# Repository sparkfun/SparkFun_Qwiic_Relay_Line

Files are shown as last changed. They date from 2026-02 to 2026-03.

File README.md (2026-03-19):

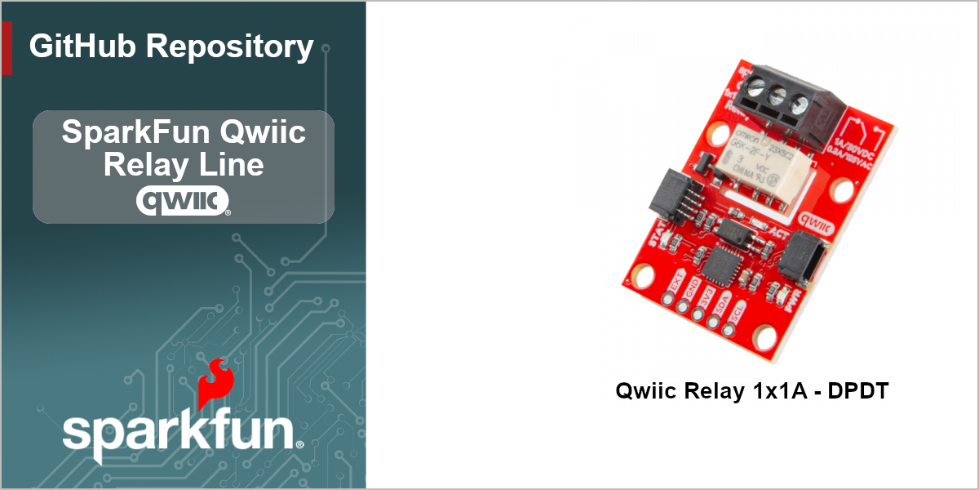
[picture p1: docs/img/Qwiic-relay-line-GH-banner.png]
SparkFun Qwiic Relay Line (https://www.sparkfun.com/sparkfun-qwiic-relay-1x1a-dpdt.html)


The SparkFun Qwiic Relay Line are a series of Qwiic compatible boards to control high power devices from a microcontroller over I<sup>2</sup>C using the Qwiic interface.

The [SparkFun Qwiic Relay - 1X1A DPDT](https://www.sparkfun.com/sparkfun-qwiic-relay-1x1a-dpdt.html) lets you control high power devices from a microcontroller over I<sup>2</sup>C. This relay breakout uses the G6K-2F-Y DC3 dual-pole/dual-throw relay from Omron Electronic Components capable of switching loads of 1A/30VDC and 0.3A/125VAC (at 40&deg;C) with very low drive currents to switch the relay. This board has one 3-pin screw terminal connector for solderless connection to one of the relay's terminals and a 0.1"-spaced plated through-hole header for connecting the second terminal. It also has options to drive the relay over I<sup>2</sup>C (via Qwiic or a soldered connection) or an external drive input such as a switch or I/O signal. Driving the relay over I<sup>2</sup>C only requires up to 5.8mA@3.3V and driving it from an external input requires up to 33mA@3.3V.

Repository Contents
-------------------

* **/Examples** - Simple Arduino examples for the Qwiic Relay Line 
* **/Hardware** - KiCad design files (.brd, .sch)
* **/docs** - Documentation files for the Qwiic Relay Line

Documentation
--------------
* **[Library](https://github.com/sparkfun/SparkFun_I2C_Expander_Arduino_Library)** - Arduino library for interfacing with 4 and 8-bit I2C GPIO Expanders.
* **[Hookup Guide](https://docs.sparkfun.com/SparkFun_Qwiic_Relay_Line/)** - Basic hookup guide for the Qwiic Relay Line.

Product Versions
----------------
* [COM-30416](https://www.sparkfun.com/sparkfun-qwiic-relay-1x1a-dpdt.html) - Qwiic Relay - 1X1A DPDT

License Information
-------------------

This product is _**open source**_! 

Please review the LICENSE.md file for license information. 

If you have any questions or concerns on licensing, please contact technical support on our [SparkFun forums](https://forum.sparkfun.com/viewforum.php?f=152).

Distributed as-is; no warranty is given.

- Your friends at SparkFun.

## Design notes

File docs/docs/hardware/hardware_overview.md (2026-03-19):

# Hardware Overview - Qwiic Relay - 1x1A DPDT 

Let's take a closer look at the components on the Qwiic Relay - 1x1A DPDT.

<figure>
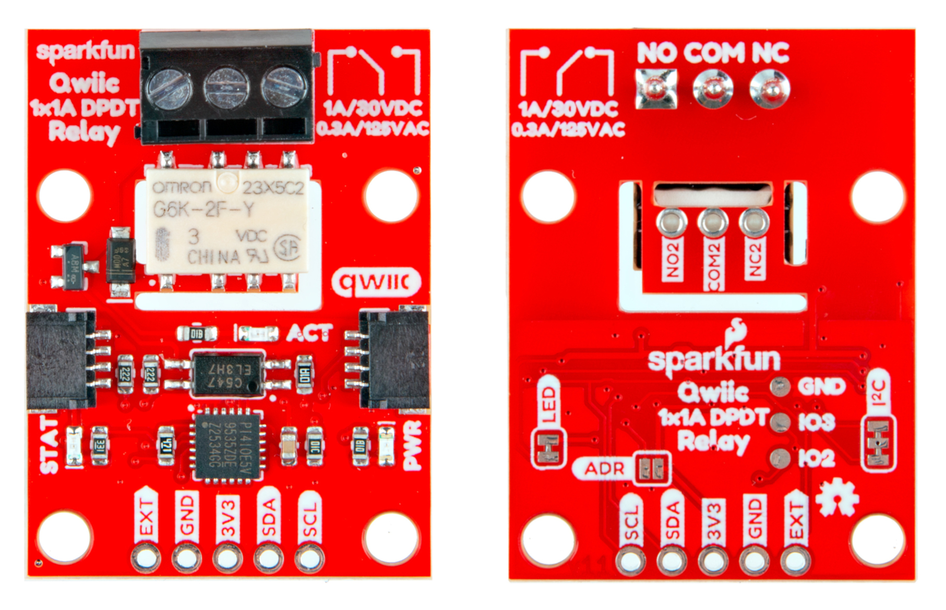
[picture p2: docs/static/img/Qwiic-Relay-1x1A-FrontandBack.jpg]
Front and Back images of the Qwiic Relay - 1X1A DPDT

</figure>

## 1A Dual-Pole/Dual-Throw Relay

The G6K-2F-Y Dual-Pole/Dual-Throw (DPDT) relay from Omron Electronic Components handles switching loads of 1A/30VDC and 0.3A/125VAC (at 40&deg;C) with very low drive currents. The design of this board lets users drive the relay over I<sup>2</sup>C or through an external drive pin. Driving the relay over I<sup>2</sup>C requires up to 5.8mA while driving it from an external source requires up to 33mA.

The board isolates the high-power side of the relay with both a physical air-gap in the PCB along with an opto-isolator circuit. For detailed information on the G6K-2F-Y, refer to the [datasheet](/ref/K106-E1.pdf).  

## Load Connections

This relay board includes two connection types for the relay's two poles. The main (COM) pole connects to a 3-pin screw terminal for solderless connection of a load. In order to conserve space on the board, the second (COM2) pole connects to three 0.1"-spaced plated through-hole pins on the bottom of the board. 

## TCA9555 I<sup>2</sup>C GPIO Expander

The Qwiic Relay uses a TCA9555 I<sup>2</sup>C GPIO Expander to control the relay over I<sup>2</sup>C. The TCA9555 is a 16-bit I/O expander that is configured in the Arduino example to have two of its pins act as outputs to control the relay's signal line and the green status LED. This allows the drive current for the relay to just be up to 5.8mA. The board sets the TCA9555's I<sup>2</sup>C address to **0x20** by default. Users can set the GPIO Expander to the alternate address, **0x21**, by closing the ADR jumper. For a complete overview of the TCA9555, refer to the [datasheet](/ref/tca9555.pdf)

## Connectors

### Qwiic Connectors

The Qwiic Relay has a pair of Qwiic connectors to power and control the board from a microcontroller over I<sup>2</sup>C. 

### PTHs

The Qwiic Relay has one 0.1"-spaced plated through-hole (PTH) header that breaks out the board's power pins, I<sup>2</sup>C pins (SDA/SCL) as well as an external drive pin to control the relay from a connected I/O pin or other external input. The external drive pin requires 33mA to drive the relay.

## LEDs

This board has three LEDs labeled **PWR**, **STAT** and **ACT**. The red Power (PWR) LED indicates when the board has power over 3.3V. The green Status (STAT) LED connects to P01 on the GPIO Expander IC. This LED can be used as a visual indicator for a variety of statuses. The example code turns it on whenever the relay is active. The green Activity (ACT) LED connects to the output of the optoisolator and turns on whenever the relay is switched on.

## Solder Jumpers

The Qwiic Relay has three solder jumpers labeled **LED**, **ADR** and **I<sup>2</sup>C**. The **LED** jumper completes the power LED circuit and is CLOSED by default. Open this jumper to disable the power LED. The **ADR** jumper controls the GPIO Expander IC's I<sup>2</sup>C address and is OPEN by default to set the I<sup>2</sup>C address to **0x20**. Close the ADR jumper to switch the GPIO Expander's I<sup>2</sup>C address to **0x21**. The **I<sup>2</sup>C** jumper pulls the I<sup>2</sup>C lines (SDA/SCL) to **3.3V** through a pair of **2.2k&ohm;** resistors. Completely open this jumper to disable pullups on the bus.

## Board Dimensions

The Qwiic Relay 1x1A - DPDT measures 1" x 1.35" (25.40mm x 34.29mm) and has four mounting holes that fit a 4-40 screw. 

<figure markdown>
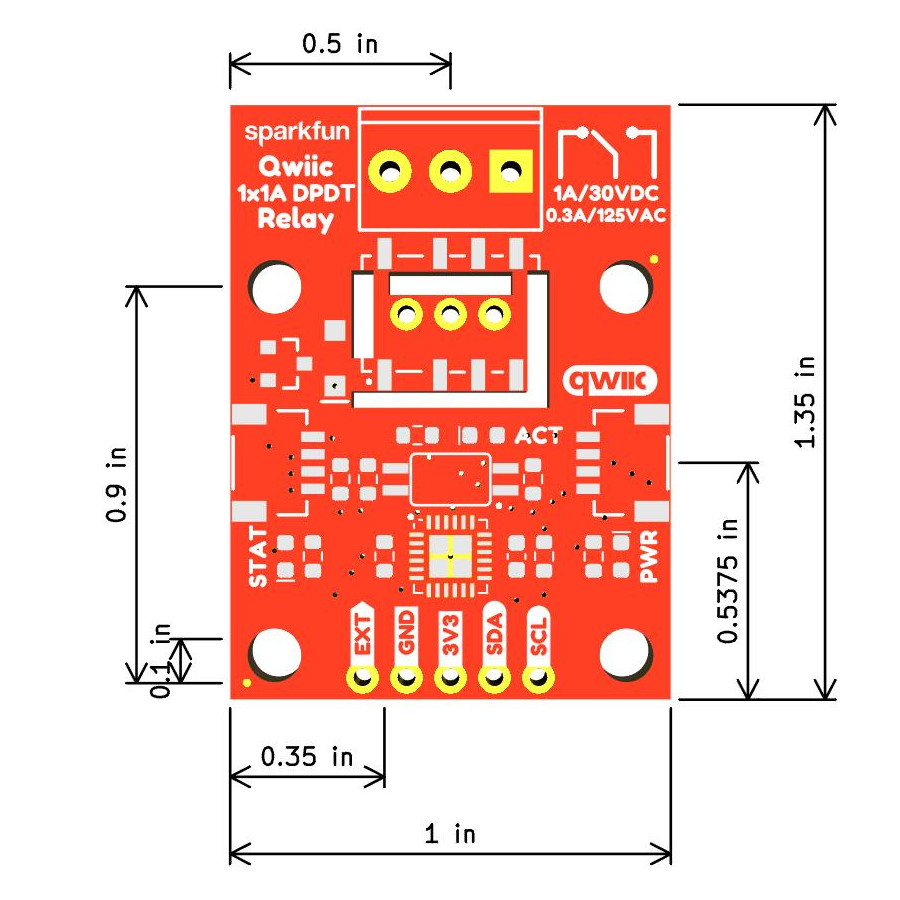
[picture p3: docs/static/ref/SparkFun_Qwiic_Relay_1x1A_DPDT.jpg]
Board Dimensions

<figcaption>Qwiic Relay 1x1A - DPDT Board Dimensions</figcaption>
</figure>

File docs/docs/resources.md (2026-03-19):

For more information on the SparkFun Qwiic Relay - 1X1A DPDT, check out the following resources:

* [Schematic](/ref/SparkFun_Qwiic_Relay_1x1A_DPDT.pdf)
* [KiCad Files](/ref/SparkFun_Qwiic_Relay_1x1A_DPDT.zip)
* [Board Dimensions](/ref/SparkFun_Qwiic_Relay_1x1A_DPDT.jpg)
* [Datasheet](/ref/K106-E1.pdf) (G6K-2F-Y DC3 DPDT Relay)
* [Datasheet](/ref/tca9555.pdf) (TCA9555 GPIO Expander)
* [SparkFun I<sup>2</sup>C Expander Arduino Library](https://github.com/sparkfun/SparkFun_I2C_Expander_Arduino_Library)
* [GitHub Repository](https://github.com/sparkfun/SparkFun_Qwiic_Relay_Line)

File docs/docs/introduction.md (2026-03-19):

---
slug: /
---

<figure>
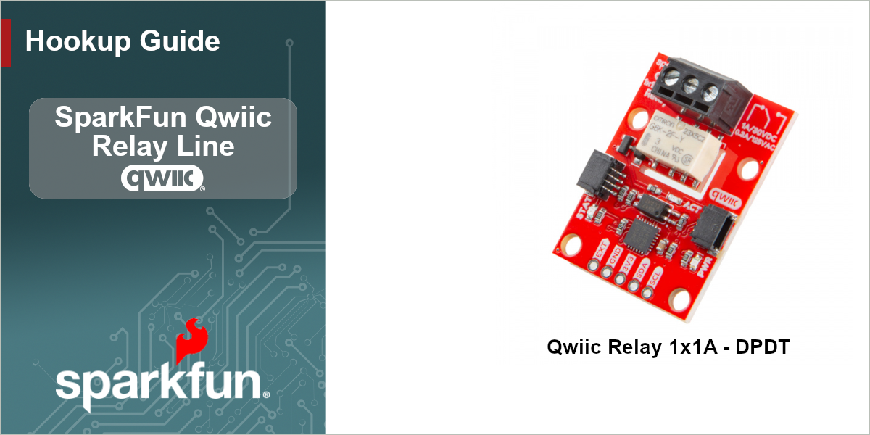
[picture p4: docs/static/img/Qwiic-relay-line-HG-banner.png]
Qwiic Relay Line Banner Image

</figure>

# Introduction

The SparkFun Qwiic Relay - 1X1A DPDT lets you control high power devices from a microcontroller over I<sup>2</sup>C. This relay breakout uses the G6K-2F-Y DC3 dual-pole/dual-throw relay from Omron Electronic Components capable of switching loads of 1A/30VDC and 0.3A/125VAC (at 40&deg;C) with very low drive currents to switch the relay. 

This board has one 3-pin screw terminal connector for solderless connection to one of the relay's terminals and a 0.1"-spaced plated through-hole header for connecting the second terminal. It also has options to drive the relay over I<sup>2</sup>C (via Qwiic or a soldered connection) or an external drive input such as a switch or I/O signal. Driving the relay over I<sup>2</sup>C only requires up to 5.8mA@3.3V and driving it from an external input requires up to 33mA@3.3V.

# Required Materials

In order to follow along with this guide you'll need the SparkFun Qwiic Relay - 1X1A DPDT along with the following items:

* [SparkFun RedBoard IoT - ESP32](https://www.sparkfun.com/sparkfun-iot-redboard-esp32-development-board.html) (Or a similar Arduino microcontroller)
* [Qwiic Cable](https://www.sparkfun.com/flexible-qwiic-cable-200mm.html)
* [USB-C Cable](https://www.sparkfun.com/usb-a-to-usb-c-cable-1m-usb-2-0-flexible-silicone.html)
* DC or AC Load

# Topics Covered

This guide contains three main sections: **Quickstart Guide**, **Hardware** and **Software**. 

The Quickstart Guide goes over how to connect a load to the Qwiic Relay - 1X1A DPDT and then control it over I<sup>2</sup>C while connected over a Qwiic cable to a SparkFun RedBoard IoT - ESP32 using the SparkFun GPIO Expander Arduino Library.

The Hardware section includes the **Hardware Overview** and provides a detailed overview of the Qwiic Relay - 1X1A DPDT. The **Hardware Assembly** page covers how to connect a load to the relay and connect the board to a microcontroller.

The Software section covers how to install and use the SparkFun GPIO Expander Arduino library with the Qwiic Relay - 1X1A DPDT.

# Resources and Support Documentation

You'll find the board design files (KiCad files & schematic), relevant documentation (datasheets, white papers, etc.) and other helpful links in the **Resources**. Lastly, the **Support** section includes a Troubleshooting page that includes any helpful tips specific to this board as well as information on how to receive technical support from SparkFun.

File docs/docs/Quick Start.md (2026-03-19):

# Quick Start Guide

In this Quick Start guide we'll go over how to assemble a single AC load to the Qwiic Relay 1X1A - DPDT and connect it to a SparkFun RedBoard IoT - ESP32 to control the relay and load using the SparkFun I<sup>2</sup>C Expander Arduino Library. 

This Quick Start guide assumes users have an understanding of how to safely wire an AC load to a relay, how to use Qwiic breakouts with Arduino development boards and how to use the Arduino IDE. If you're not familiar with these concepts we recommend reading through the rest of the guide before proceeding to assemble the Qwiic Relay.

## Qwiic Assembly

We'll start by connecting the Qwiic Relay 1X1A - DPDT to the RedBoard IoT - ESP32 using a Qwiic cable. Simply plug one end into one of the Qwiic Relay's Qwiic connectors and the other into the RedBoard IoT's Qwiic connector like the photo below:

<figure markdown>
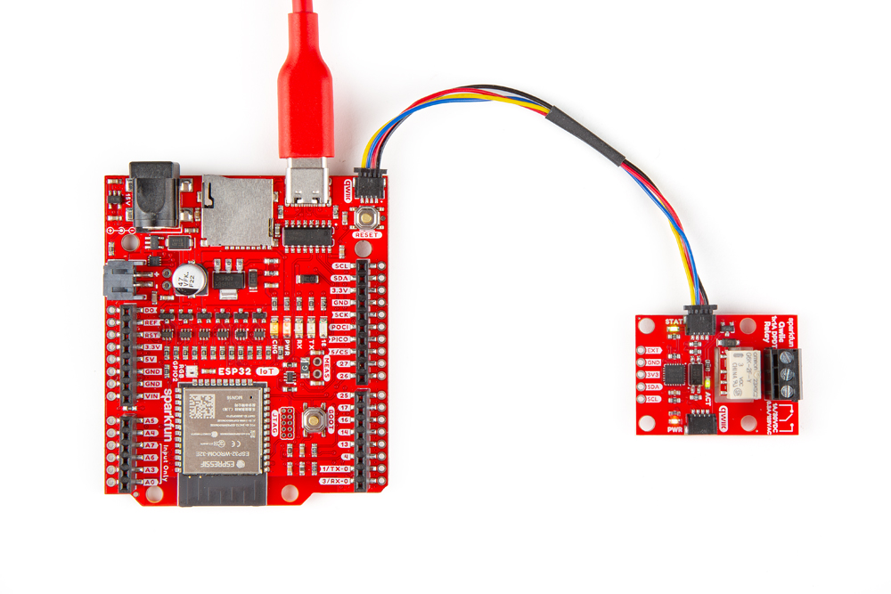
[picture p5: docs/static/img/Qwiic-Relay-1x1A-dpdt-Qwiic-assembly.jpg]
Completed Qwiic assembly to the RedBoard IoT - ESP32

<figcaption>Qwiic Relay 1x1A - DPDT connected to the RedBoard IoT - ESP32 over Qwiic.</figcaption>
</figure>

## Relay Load Assembly

:::warning

 Not sure about what color insulation wiring is used in you region? Check out the [standard wire insulation colors listed online](https://en.wikipedia.org/wiki/Electrical_wiring) for reference. If you are unsure about the standard wiring color in your region, please consult a certified electrician to connect to the AC input voltage side. Make sure the cable is not plugged into the wall as you cut into the wire in the following section.

:::

With the Qwiic Relay 1x1A connected to the RedBoard, let's prepare the wiring for the AC load with the following steps:

* Start by cutting the live AC line (usually black or red) and stripping a small amount of insulation away from the ends of the cut wire.
* Insert one end of the cut wire into the `COM` screw terminal and tighten it to secure the wire.
* Insert the other end of the cut wire either into the `NC` or `NO` screw terminal depending on whether the device will normally be on or off.
    * If the device will normally be **on** and switched **off**, connect this end to `NC`.
    * If the device will normally be **off** and switched **on**, connect this end to `NO`.

<figure markdown>
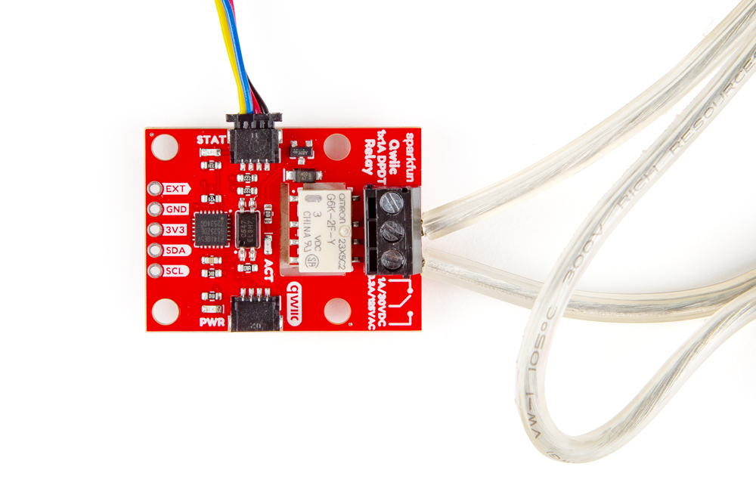
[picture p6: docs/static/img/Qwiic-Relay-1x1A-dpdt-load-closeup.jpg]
Close up photo of the AC load wires connected to the Qwiic Relay screw terminals

<figcaption>AC Load connected to Qwiic Relay 1x1A - DPDT screw terminals.</figcaption>
</figure>

:::danger

 Warning! Make sure that your wires connecting to the wall outlet are secure and are rated to handle the current! Please be careful when handling the contacts when the cable is plugged into a wall outlet. Touching the contacts while powered could result in injury.

 Looking for information about safety and insulation? Check out the notes about [Safety and Insulation](https://learn.sparkfun.com/tutorials/beefcake-relay-control-hookup-guide#safety-and-insulation) from our Beefcake Relay Control Kit. 

:::

With everything connected up, your circuit should look similar to the photo below. Now let's upload some code to turn the load on and off.

<figure markdown>
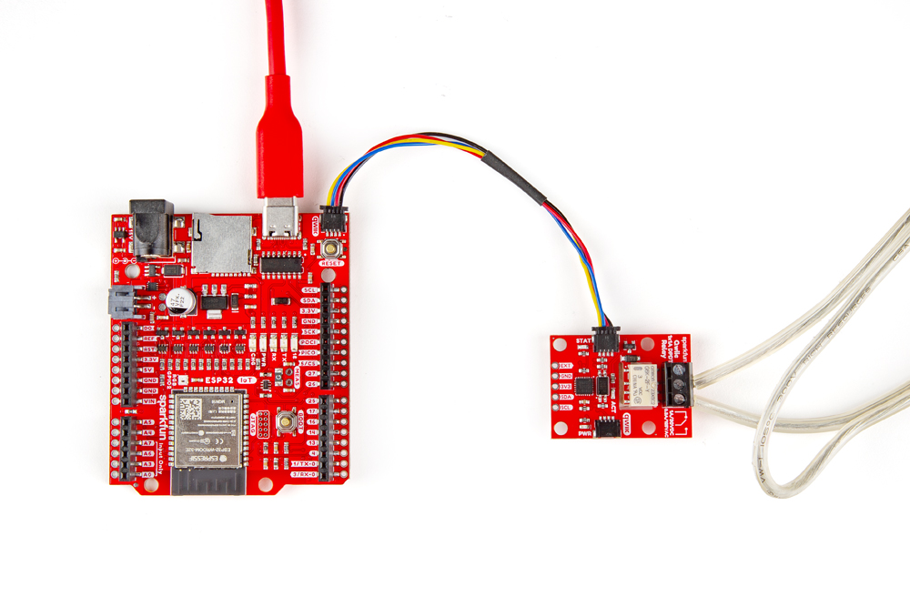
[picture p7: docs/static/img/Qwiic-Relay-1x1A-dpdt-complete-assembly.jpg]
Completed assembly photo

<figcaption>Completed Qwiic Relay 1x1A - DPDT assembly.</figcaption>
</figure>

## Toggle Relay LED Arduino Example

This example toggles the relay and both green status LEDs on and off every second. This example uses the [SparkFun I2C Expander Arduino Library](https://github.com/sparkfun/SparkFun_I2C_Expander_Arduino_Library) and can be found in the [Examples folder](https://github.com/sparkfun/SparkFun_Qwiic_Relay_Line/tree/main/Examples) of the Qwiic Relay Line GitHub repository. Follow the steps below to upload the code.

* Open the [Arduino IDE](https://docs.arduino.cc/software/ide-v2/tutorials/getting-started-ide-v2/).
* Open the [Library Manager](https://docs.arduino.cc/software/ide-v2/tutorials/ide-v2-installing-a-library/) tool, search for "SparkFun I2C Expander" and install the latest version. 
* Either download the example from the [Examples folder](https://github.com/sparkfun/SparkFun_Qwiic_Relay_Line/tree/main/Examples) of the Qwiic Relay Line library or copy the example code into a blank Arduino sketch.
* Select your Board (SparkFun RedBoard IoT - ESP32 or other board) and Port and click "Upload".
* After the code compiles and finishes uploading, the AC load and green LEDs should be turning on and off every second. You can open the [serial monitor](https://docs.arduino.cc/software/ide-v2/tutorials/ide-v2-serial-monitor/) with the baud set to **115200** to view the serial printout of the code in case there are any errors.

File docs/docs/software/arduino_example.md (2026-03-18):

# Example - Toggle Relay LED

We've written a simple sketch for the Qwiic Relay 1X1A - DPDT to toggle the relay and status LEDs on and off every second. You can find the example in the [Examples Folder](https://github.com/sparkfun/SparkFun_Qwiic_Relay_Line/tree/main/Examples) in the Qwiic Relay GitHub Repository. Download the example or copy the code into an empty sketch.

Next, select the Board and Port (in our case the SparkFun RedBoard IoT - ESP32) and click the "Upload" button. Once the code finishes compiling and uploading, you should see the relay toggling the load and both green LEDs on the Qwiic Relay 1x1A on and off every second. If you do not see this behavior, open the [serial monitor](https://docs.arduino.cc/software/ide-v2/tutorials/ide-v2-serial-monitor/) with the baud set to **115200** to view the serial printout of the code in case there are any errors.

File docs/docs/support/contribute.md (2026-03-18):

# Contribute

## Improve our Documentation

All of this documentation can be modified by you! Please help us make it better.

* These pages are contained in the [`docs` folder of the SparkFun Qwiic Relay Line repository](https://github.com/sparkfun/SparkFun_Qwiic_Relay_Line/tree/main/docs).

### Submit a Correction

1. Fork this repo
2. Add your corrections or improvements to the markdown file
3. File a pull request with your changes, and enjoy making the ~~words~~ ~~worlds~~ world a better place.
    * Once received, the documentation specialist will automatically be notified.
    * We will review your suggested improvements to make sure they are correct and fit within our documentation standards.

## Improve our Hardware Design

This hardware design is open-source! Please help us make it better.

* Our board design files are contained in the [`Hardware` folder of the SparkFun Qwiic Relay Line repository](https://github.com/sparkfun/SparkFun_Qwiic_Relay_Line_IoT_9DoF/tree/main/Hardware).

### Submit a Design Improvement

1. Fork this repo
2. Add your design improvements
3. File a pull request with your changes, and enjoy making the ~~words~~ ~~worlds~~ world a better place.
    * Once received, the engineer in charge of the original design will automatically be notified.
    * We will review your suggested improvements, if they are within our board design standards and meet our product design requirements, we will flag these changes for our next board revision. *(Please note, that even if your suggestion is accepted, these changes may not be immediate. We may have to cycle through our current product inventory first.)*

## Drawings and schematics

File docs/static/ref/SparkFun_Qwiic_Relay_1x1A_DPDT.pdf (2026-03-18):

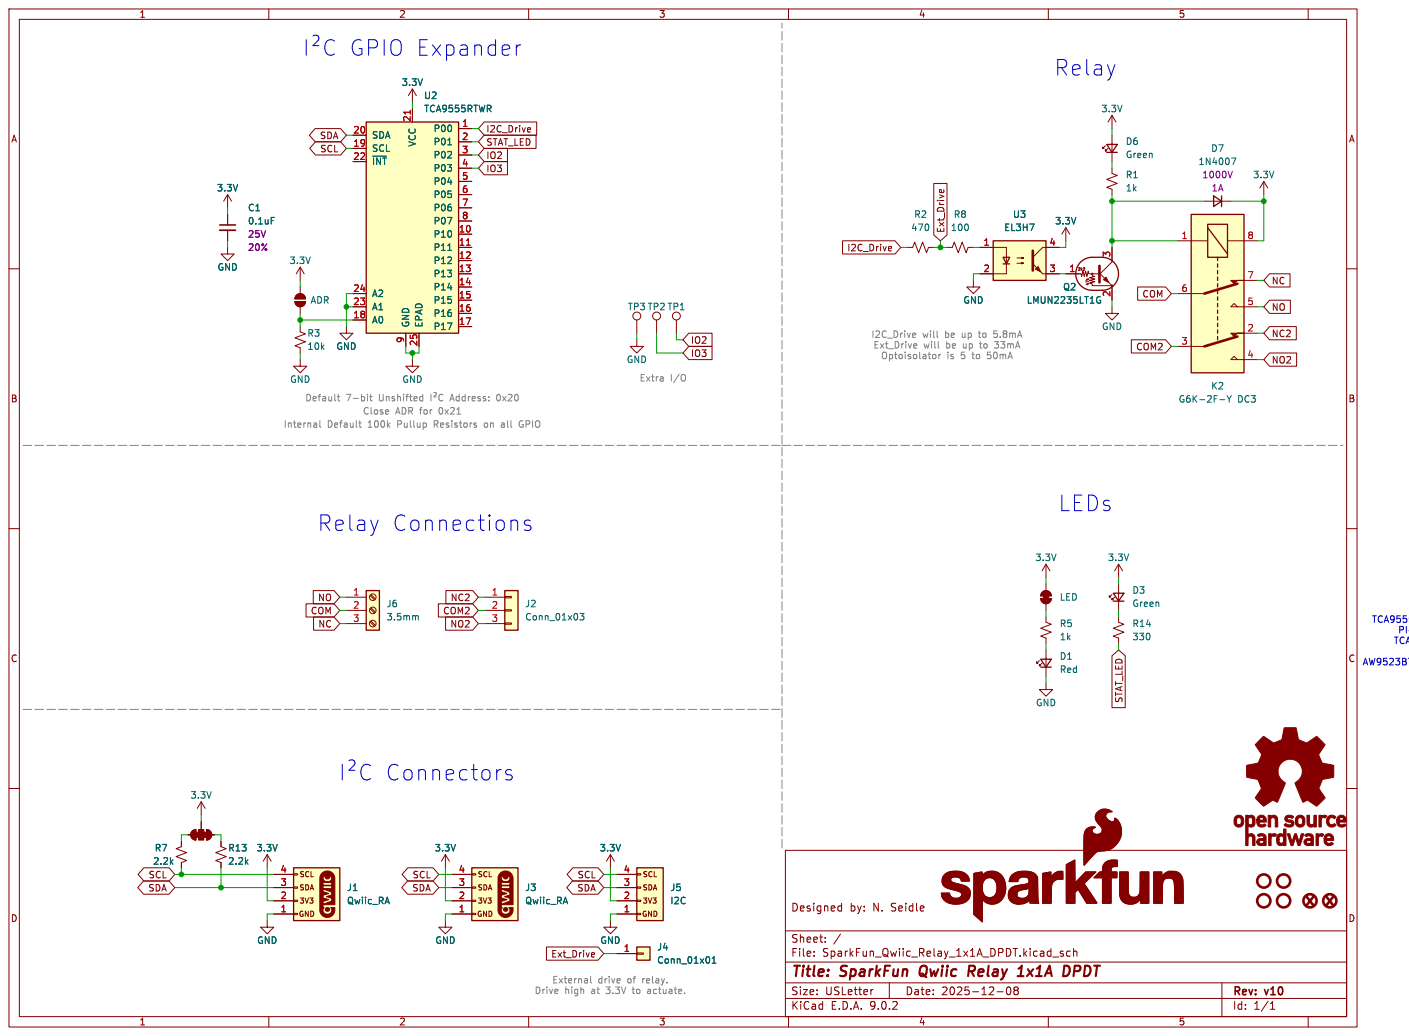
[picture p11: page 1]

I2C_Drive will be up to 5.8mA

External drive of relay. Drive high at 3.3V to actuate.

Id: 1/1 Title: SparkFun Qwiic Relay 1x1A DPDT

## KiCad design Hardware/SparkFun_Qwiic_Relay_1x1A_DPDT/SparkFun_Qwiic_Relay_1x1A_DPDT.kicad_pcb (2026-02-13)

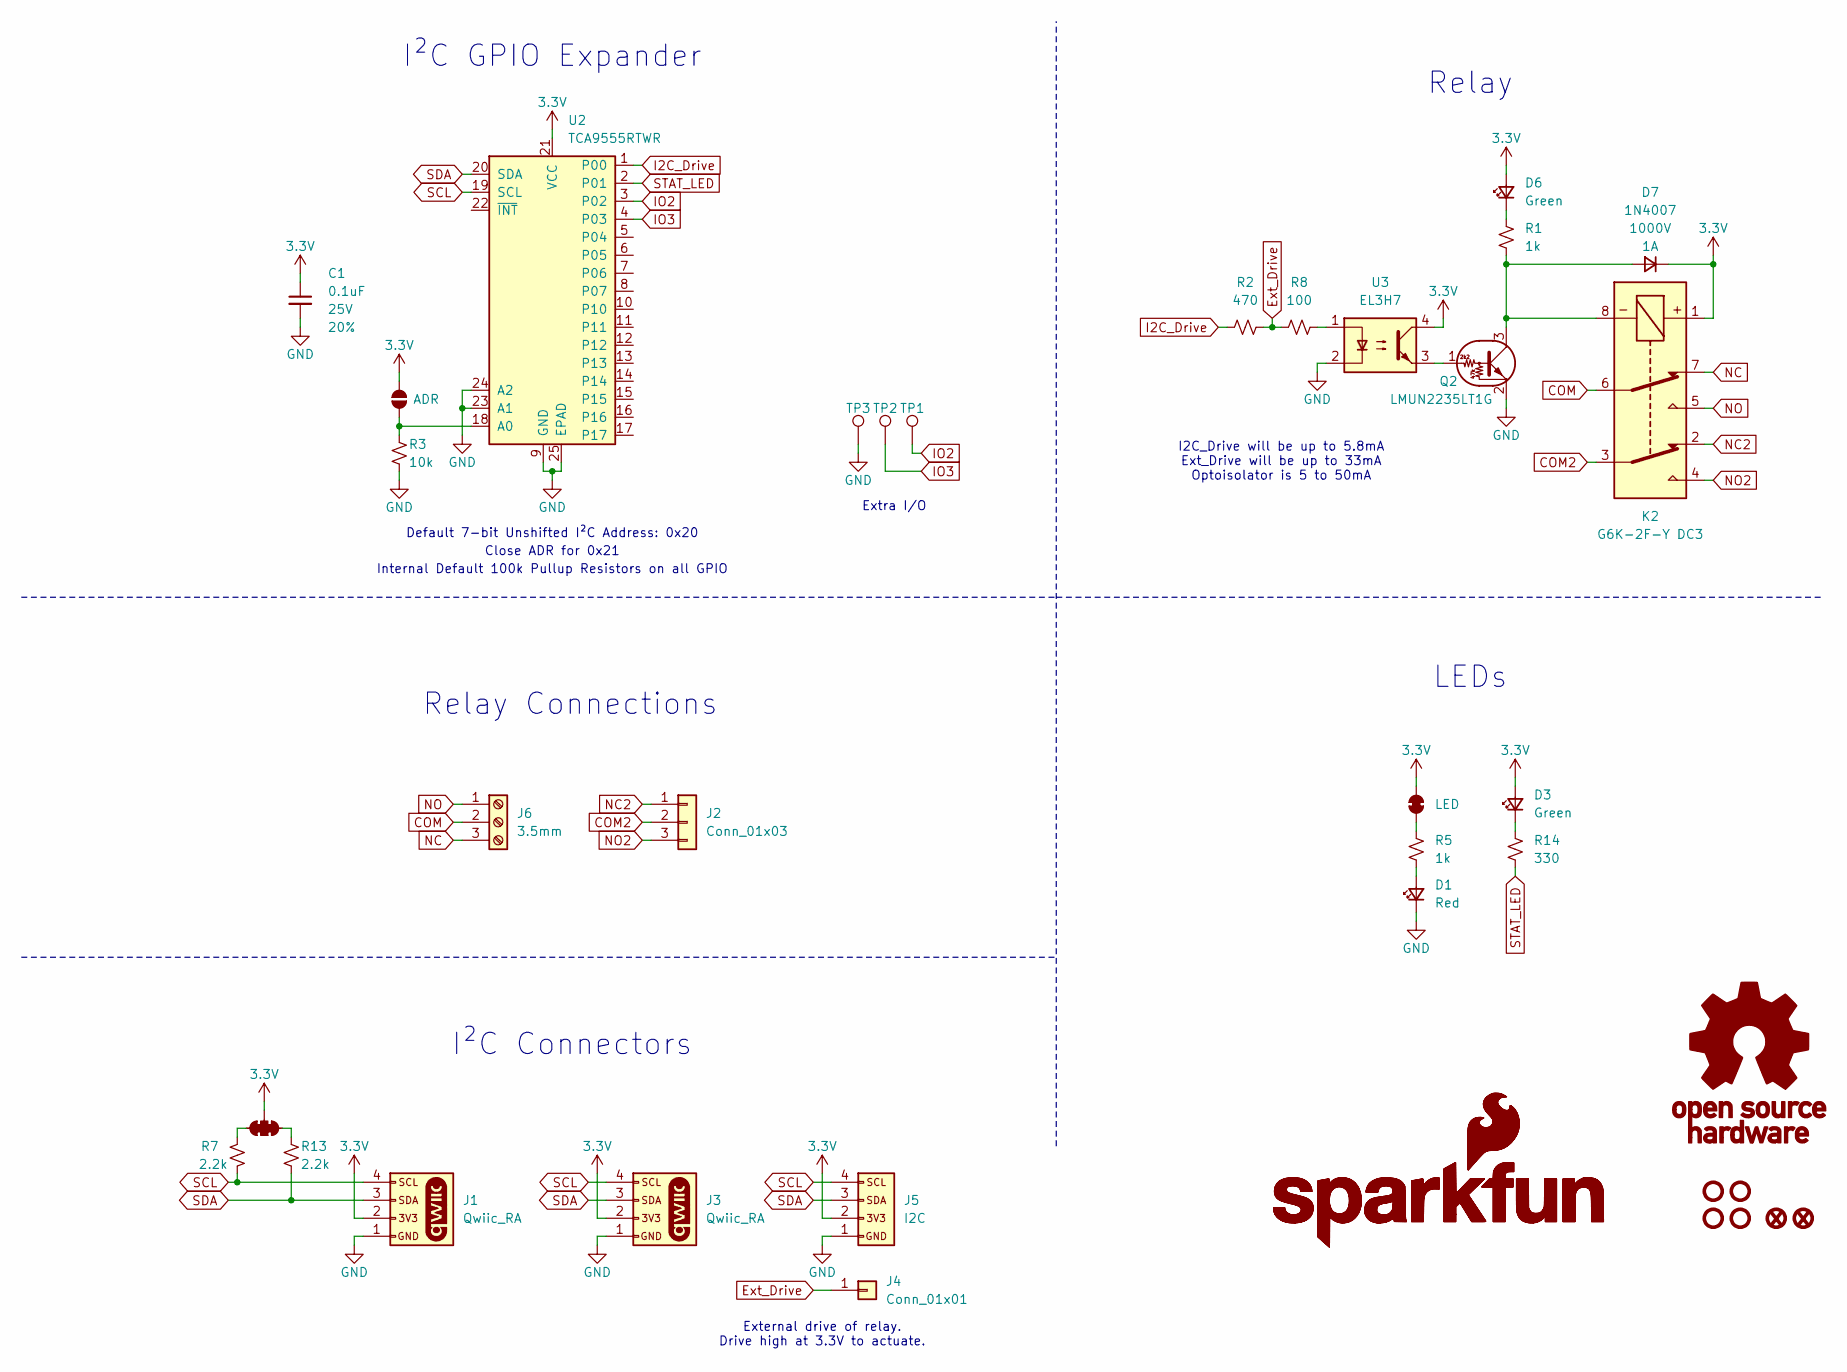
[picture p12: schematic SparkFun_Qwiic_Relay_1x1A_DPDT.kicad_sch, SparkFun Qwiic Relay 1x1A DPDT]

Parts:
C1: 0.1uF; C_0603_1608Metric; Voltage 25V; Tolerance 20%
D1: Red; LED_0603_1608Metric_Red
D3, D6: Green; LED_0603_1608Metric_Green
D7: 1N4007; SOD-123
FID3, FID4: Fiducial_0.5mm; Fiducial_0.5mm_Mask1mm
G1: OSHW_Logo; Creative_Commons_License
G3: SparkFun_Logo
G5: SparkFun_Logo; SparkFun_Logo_8mm
J1, J3: Qwiic_RA; JST_1x04_P1.0mm_Horizontal_SMD
J2: Conn_01x03; 1x03_P2.54mm
J4: Conn_01x01; 1x01_P2.54mm
J5: I2C; 1x04_P2.54mm
J6: 3.5mm; ScrewTerminal_1x03_P3.5mm_Horizontal_Black
JP1: ADR; Jumper_2_NO
JP4: LED; Jumper_2_NC_Trace
JP6: Jumper_3_NC-2_Trace
K2: G6K-2F-Y DC3; Relay_DPDT_1A_10.0x6.5mm_SMD
Q2: LMUN2235LT1G; SOT23-3
R1, R5: 1k; R_0603_1608Metric
R2: 470; R_0603_1608Metric
R3: 10k; R_0603_1608Metric
R7, R13: 2.2k; R_0603_1608Metric
R8: 100; R_0603_1608Metric
R14: 330; R_0603_1608Metric
ST1, ST2, ST3, ST4: Standoff
TP1, TP2, TP3: 1.25mm; TestPoint-1.25mm
U2: TCA9555RTWR; QFN-24-1EP_4x4mm_P0.5mm_EP2.45x2.45mm
U3: EL3H7; SSOP-4

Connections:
3.3V: C1.1, D3.2 (A), D6.2 (A), D7.1 (K), J1.2, J3.2, J5.2, JP1.2 (B), JP4.2 (B), JP6.2 (B), K2.1, U2.21 (VCC), U3.4
COM: J6.2, K2.6
COM2: J2.2, K2.3
Ext_Drive: J4.1, R2.2, R8.1
GND: C1.2, D1.1 (K), J1.1, J3.1, J5.1, Q2.2 (E), R3.1, TP3.1, U2.9 (GND), U2.23 (A1), U2.24 (A2), U2.25 (EPAD), U3.2
I2C_Drive: R2.1, U2.1 (P00)
IO2: TP1.1, U2.3 (P02)
IO3: TP2.1, U2.4 (P03)
NC: J6.3, K2.7
NC2: J2.1, K2.2
NO: J6.1, K2.5
NO2: J2.3, K2.4
unnamed: D1.2 (A), R5.1
unnamed: D3.1 (K), R14.1
unnamed: D6.1 (K), R1.2
unnamed: D7.2 (A), K2.8, Q2.3 (C), R1.1
unnamed: JP1.1 (A), R3.2, U2.18 (A0)
unnamed: JP4.1 (A), R5.2
unnamed: JP6.1 (A), R13.2
unnamed: JP6.3 (C), R7.2
unnamed: Q2.1 (B), U3.3
unnamed: R8.2, U3.1
SCL: J1.4, J3.4, J5.4, R7.1, U2.19 (SCL)
SDA: J1.3, J3.3, J5.3, R13.1, U2.20 (SDA)
STAT_LED: R14.2, U2.2 (P01)

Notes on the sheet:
Internal Default 100k Pullup Resistors on all GPIO
Default 7-bit Unshifted I²C Address: 0x20
I²C GPIO Expander
I²C Connectors
External drive of relay. Drive high at 3.3V to actuate.
Extra I/O
LEDs
Relay
Close ADR for 0x21
Relay Connections
I2C_Drive will be up to 5.8mA Ext_Drive will be up to 33mA Optoisolator is 5 to 50mA

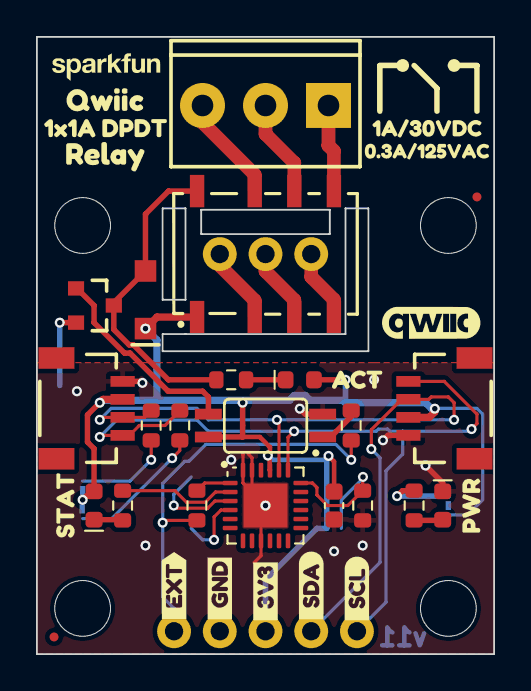
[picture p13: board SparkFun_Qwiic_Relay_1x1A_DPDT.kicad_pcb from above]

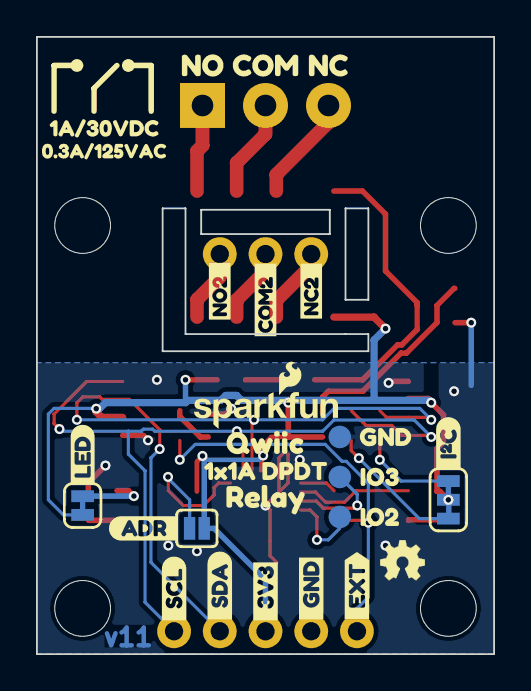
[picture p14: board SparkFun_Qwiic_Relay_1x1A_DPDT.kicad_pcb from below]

Board: 2 copper layers, 25.4 x 34.3 mm, 72 parts (30 on the bottom side), 25 nets.

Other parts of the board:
Ref**: Val**; OSHW_Logo_2.5mm
kibuzzard-689A66E2: G***; kibuzzard-689A66E2
kibuzzard-689A66E9: G***; kibuzzard-689A66E9
kibuzzard-689A66EE: G***; kibuzzard-689A66EE
kibuzzard-689A66F4: G***; kibuzzard-689A66F4
kibuzzard-689A642E: G***; kibuzzard-689A642E
kibuzzard-689A6711: G***; kibuzzard-689A6711
kibuzzard-689A6718: G***; kibuzzard-689A6718
kibuzzard-689A6721: G***; kibuzzard-689A6721
kibuzzard-689A6728: G***; kibuzzard-689A6728
kibuzzard-689A6796: G***; kibuzzard-689A6796
kibuzzard-695DDFCB: G***; kibuzzard-695DDFCB
kibuzzard-69310F2E, kibuzzard-69310F2E#2: G***; kibuzzard-69310F2E
kibuzzard-69310F7D: G***; kibuzzard-69310F7D
kibuzzard-69310F28, kibuzzard-69310F28#2: G***; kibuzzard-69310F28
kibuzzard-69310F79: G***; kibuzzard-69310F79
kibuzzard-69310F83: G***; kibuzzard-69310F83
kibuzzard-69339D3B: G***; kibuzzard-69339D3B
kibuzzard-69339D34: G***; kibuzzard-69339D34
kibuzzard-693110A5: G***; kibuzzard-693110A5
kibuzzard-693110C2: G***; kibuzzard-693110C2
kibuzzard-693110C5: G***; kibuzzard-693110C5
kibuzzard-693716BB: G***; kibuzzard-693716BB
kibuzzard-693716F7: G***; kibuzzard-693716F7
kibuzzard-693717B6: G***; kibuzzard-693717B6
kibuzzard-6931071F: G***; kibuzzard-6931071F
kibuzzard-6937168C, kibuzzard-6937168C#2: G***; kibuzzard-6937168C
kibuzzard-69311012: G***; kibuzzard-69311012
kibuzzard-69325721: G***; kibuzzard-69325721
kibuzzard-69371669, kibuzzard-69371669#2: G***; kibuzzard-69371669
kibuzzard-69371817: G***; kibuzzard-69371817
kibuzzard-69371825: G***; kibuzzard-69371825

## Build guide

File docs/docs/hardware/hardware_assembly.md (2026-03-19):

---
sidebar_position: 1
---

# Hardware Assembly - Qwiic Relay - 1x1A DPDT

## Qwiic Assembly

We'll start by connecting the Qwiic Relay to the RedBoard IoT - ESP32. Just plug one end of the Qwiic cable into the Qwiic Relay and the other into the RedBoard IoT - ESP32 like the photo below:

<figure markdown>
The Qwiic Relay 1x1A connected to the RedBoard IoT - ESP32 with a Qwiic cable
<figcaption>The Qwiic Relay 1X1A - DPDT is connected to the RedBoard IoT - ESP32 with a Qwiic cable.</figcaption>
</figure>

## AC Load Assembly

:::warning

Make sure the cable is not plugged into the wall as you cut into the wire in the following section. Not sure about what color insulation wiring is used in you region? Check out the [standard wire insulation colors listed online](https://en.wikipedia.org/wiki/Electrical_wiring) for reference. If you are unsure about the standard wiring color in your region, please consult a certified electrician to connect to the AC input voltage side. 

:::

* Start by cutting the live AC line (usually black or red) and stripping a small amount of insulation away from the ends of the cut wire.
* Insert one end of the cut wire into the `COM` screw terminal and tighten it to secure the wire.
* Insert the other end of the cut wire either into the `NC` or `NO` screw terminal depending on whether the device will normally be on or off.
    * If the device will normally be **on** and switched **off**, connect this end to `NC`.
    * If the device will normally be **off** and switched **on**, connect this end to `NO`.

We connected the AC load to normally be off so the wires in the photo connect to the `COM` and `NO` terminals:

<figure markdown>
Close up photo of the AC load wires connected to the Qwiic Relay screw terminals
<figcaption>AC Load connected to Qwiic Relay 1x1A - DPDT screw terminals.</figcaption>
</figure>

:::danger

 Warning! Make sure that your wires connecting to the wall outlet are secure and are rated to handle the current! Please be careful when handling the contacts when the cable is plugged into a wall outlet. Touching the contacts while powered could result in injury.

 Looking for information about safety and insulation? Check out the notes about [Safety and Insulation](https://learn.sparkfun.com/tutorials/beefcake-relay-control-hookup-guide#safety-and-insulation) from our Beefcake Relay Control Kit. 

:::

With everything connected up, your circuit should look similar to the photo below. Now let's upload some code to turn the load on and off.

<figure markdown>
Completed assembly photo
<figcaption>Completed Qwiic Relay 1x1A - DPDT assembly.</figcaption>
</figure>

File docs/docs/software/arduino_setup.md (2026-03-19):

# Arduino Setup

## Arduino Tutorials

This example assumes you are using the latest version of the Arduino IDE on your desktop. If this is your first time using Arduino IDE, library, or board add-on, please review the following tutorials.

* [Installing the Arduino IDE](https://learn.sparkfun.com/tutorials/installing-arduino-ide)
* [Installing an Arduino Library](https://learn.sparkfun.com/tutorials/installing-an-arduino-library)
* [Installing Board Definitions in the Arduino IDE](https://learn.sparkfun.com/tutorials/installing-board-definitions-in-the-arduino-ide)

## SparkFun I<sup>2</sup>C Expander Arduino Library

The SparkFun I2C Expander Library makes working with 4-bit and 8-bit I2C digital I/O expanders very easy.. You can install the library with the Arduino [Library manager](https://docs.arduino.cc/software/ide-v2/tutorials/ide-v2-installing-a-library/) tool by searching for **"SparkFun I2C Expander"**. If you'd prefer a manual install, you can download a ZIP of the library [here](https://github.com/sparkfun/SparkFun_I2C_Expander_Arduino_Library/archive/refs/heads/main.zip).

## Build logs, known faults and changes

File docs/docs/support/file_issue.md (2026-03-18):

# Submit Issues

## Support

If you need technical assistance and more information on a product that is not working as you expected, visit the [SparkFun Community](https://community.sparkfun.com). The community forums are monitored by the SparkFun Technical Support Team and the SparkFun community as a whole.

## Existing Issue

Spot something wrong? Please check the list of reported and fixed issues  .  in this repository.

## Discrepancies in the Documentation

All of this documentation can be modified by you! Please help us make it better.

* The documentation files for these pages are contained in the [`docs` folder of the SparkFun Qwiic Relay Line repository](https://github.com/sparkfun/SparkFun_Qwiic_Relay_Line/tree/main/docs).

### Spot something wrong?

If a section of the documentation is incorrect, please [open an issue](https://github.com/sparkfun/SparkFun_Qwiic_Relay_Line/issues) and let us know.

### Do you have a suggested correction?

1. With a GitHub account, fork this repo
2. Add your correction(s) or improvement(s) to the markdown file(s)
3. File a pull request with your changes, and enjoy making the ~~words~~ ~~worlds~~ world a better place.
    * Once received, the documentation specialist will automatically be notified.
    * We will review your suggested improvement(s) to make sure they are correct and fit within our documentation standards.

## Problems in the Hardware Design

All of our designs are open-source! Please help us make it better.

* Our board design files are contained in the [`Hardware` folder of the SparkFun Qwiic Relay Line repository](https://github.com/sparkfun/SparkFun_Qwiic_Relay_Line/tree/main/Hardware).

### Does something not make sense?

If part of the design is confusing, please [open an issue](https://github.com/sparkfun/SparkFun_Qwiic_Relay_Line/issues) and let us know.

### Did we forget to include an important function of the board?

Please keep in mind that we may intentionally exclude certain functions of the board to meet our product design requirements.

If part of the board's functionality is missing, please [open an issue](https://github.com/sparkfun/SparkFun_Qwiic_Relay_Line/issues) and file a feature request.

### Do you wish to contribute directly to improving the board design?

1. With a GitHub account, Fork this repo
2. Add your design improvement(s)
3. File a pull request with your changes, and enjoy making the ~~words~~ ~~worlds~~ world a better place.
    * Once received, the engineer in charge of the original design will automatically be notified.
    * We will review your suggested improvement(s), if they are within our board design standards and meet our product design requirements, we will flag these changes for our next board revision. *(Please note, that even if your suggestion is accepted, these changes may not be immediate. We may have to cycle through our current product inventory first.)*

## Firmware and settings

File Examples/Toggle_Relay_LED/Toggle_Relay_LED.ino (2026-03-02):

/*
  Using the Qwiic Relay
  By: Nathan Seidle
  SparkFun Electronics
  Date: February 12, 2026

  License: This code is public domain, please do whatever you want!

  Feel like supporting our work? Buy a board from SparkFun!
  https://www.sparkfun.com/products/30416 - Qwiic 1x1A DPDT Relay
  https://www.sparkfun.com/products/17047 - Qwiic GPIO
  https://www.sparkfun.com/products/26784 - Qwiic Power Switch
  https://www.sparkfun.com/products/26851 - Qwiic Directional Pad

  This example demonstrates how to turn the relay on/off.

  Hardware Connections:
  Plug the Qwiic Relay into a Qwiic enabled board (SparkFun Thing Plus C, RedBoard, RedBoard IoT, etc)
  If you don't have a platform with a Qwiic connection use the SparkFun Qwiic Breadboard Jumper (https://www.sparkfun.com/products/17912)
  Open the serial monitor at 115200 baud to see the output
*/

#include <SparkFun_I2C_Expander_Arduino_Library.h> // Click here to get the library: http://librarymanager/All#SparkFun_I2C_Expander_Arduino_Library

//The Qwiic Relay Line uses a 16-bit GPIO expander, the PCA5555
SFE_PCA95XX io(PCA95XX_PCA9555); // Create a PCA9555 instance

void setup()
{
  Serial.begin(115200);
  delay(250);
  Serial.println("SparkFun PCA95XX example");

  Wire.begin();

  // Initialize the PCA955x at its default address (0x20)
  if (io.begin() == false)
  {
    Serial.println("PCA95xx not detected. Please check wiring. Freezing...");
    while (true);
  }

  // pinMode can be used to set an I/O as OUTPUT or INPUT
  for (int i = 0; i < 4; i++)
  {
    io.pinMode(i, OUTPUT);
  }
}

void loop()
{
    io.digitalWrite(0, HIGH); // Turn relay on
    io.digitalWrite(1, LOW); // Turn LED on
    Serial.println("Relay on");
    delay(2500);

    io.digitalWrite(0, LOW); // Turn relay off
    io.digitalWrite(1, HIGH); // Turn LED off
    Serial.println("Relay off");
    delay(2500);
}

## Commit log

2025-12-08 Add 1x1A DPDT
    [SparkFun_Qwiic_Relay_1x1A_DPDT.kicad_pcb, SparkFun_Qwiic_Relay_1x1A_DPDT.kicad_sch]
2026-01-07 Post review update
    [SparkFun_Qwiic_Relay_1x1A_DPDT.kicad_pcb, SparkFun_Qwiic_Relay_1x1A_DPDT.kicad_sch]
2026-02-13 Fix polarized relay. Increase version on PCB and SCH.
    [SparkFun_Qwiic_Relay_1x1A_DPDT.kicad_pcb, SparkFun_Qwiic_Relay_1x1A_DPDT.kicad_sch]

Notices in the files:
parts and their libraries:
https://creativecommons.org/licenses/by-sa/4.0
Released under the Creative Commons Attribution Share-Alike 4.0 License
